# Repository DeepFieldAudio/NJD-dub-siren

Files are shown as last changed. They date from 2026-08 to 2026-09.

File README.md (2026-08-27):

Hello!

All you have here is the work on wich i spent countless hours and that i'm really happy to share with you.
If you are about to make your own version of this preamp, please share it Under the same conditions as i did.
Also, if you happen to discover mistakes that i made, or ways to improve the design, or you just built your own NJD,
then please share it with me and the rest of the world. I would love to see your builds!!

NJD V1 DOC.pdf is the complete documentation, it includes schematic, BOM, details of the pcb, wiring diagram,
and a buying list allowing you to directly access a basket at tme.eu.
GERBER NJD V1.zip is the file you need to upload on the website of the pcb manufacturer of your choice to get the pcb built.
ibom.html is an interactive bom, making it easier to build the pcb
you will also find all the kicad files that you can use to make your own mods of the design

contact me at deep field audio on instagram and facebook

this work shall remain open source and free.

Nélo Breuiller

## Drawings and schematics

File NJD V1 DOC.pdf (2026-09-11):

# DEEP FIELD

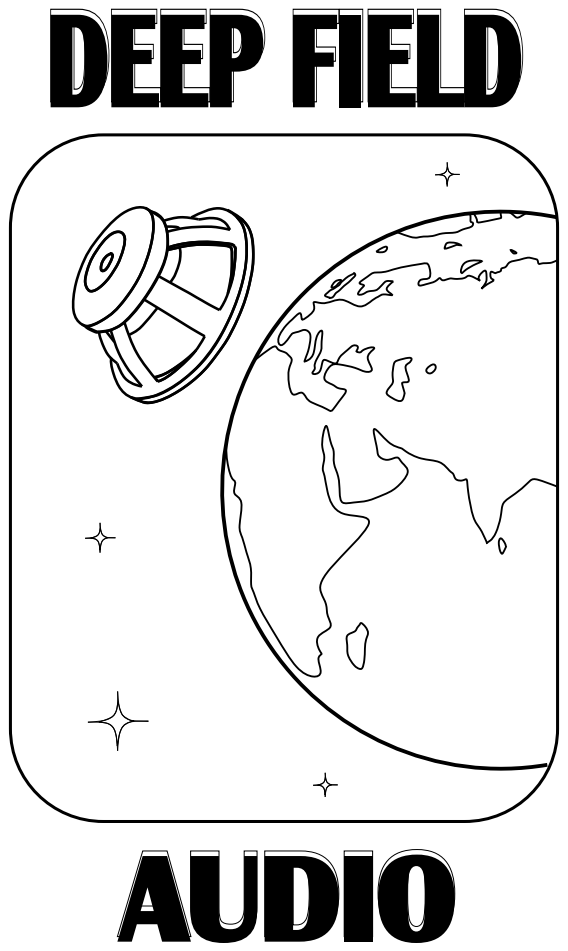
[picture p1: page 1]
AUDIO

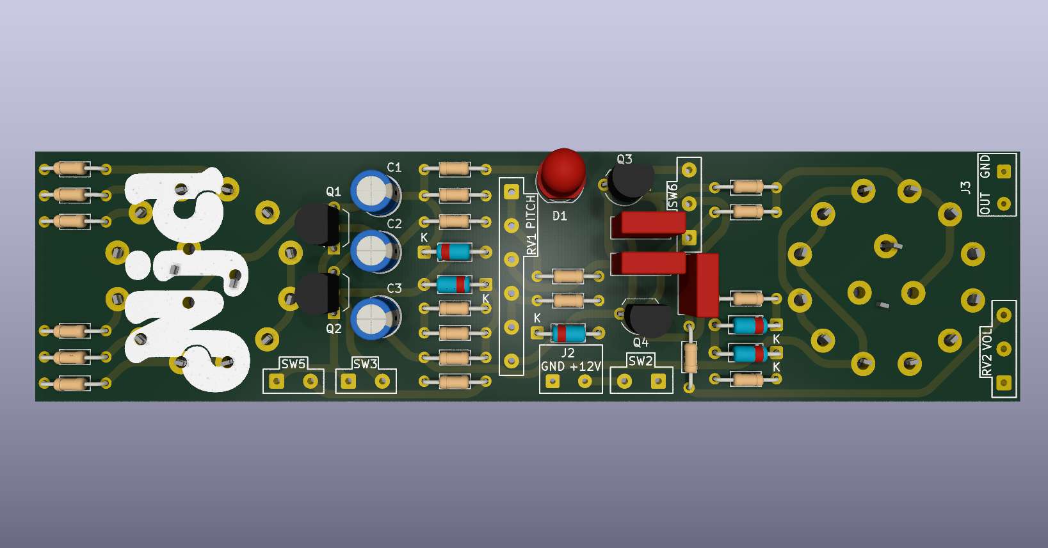
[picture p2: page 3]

1 | 2 | 3 | 4 | 5 | 6

AB

C

D

AB

C

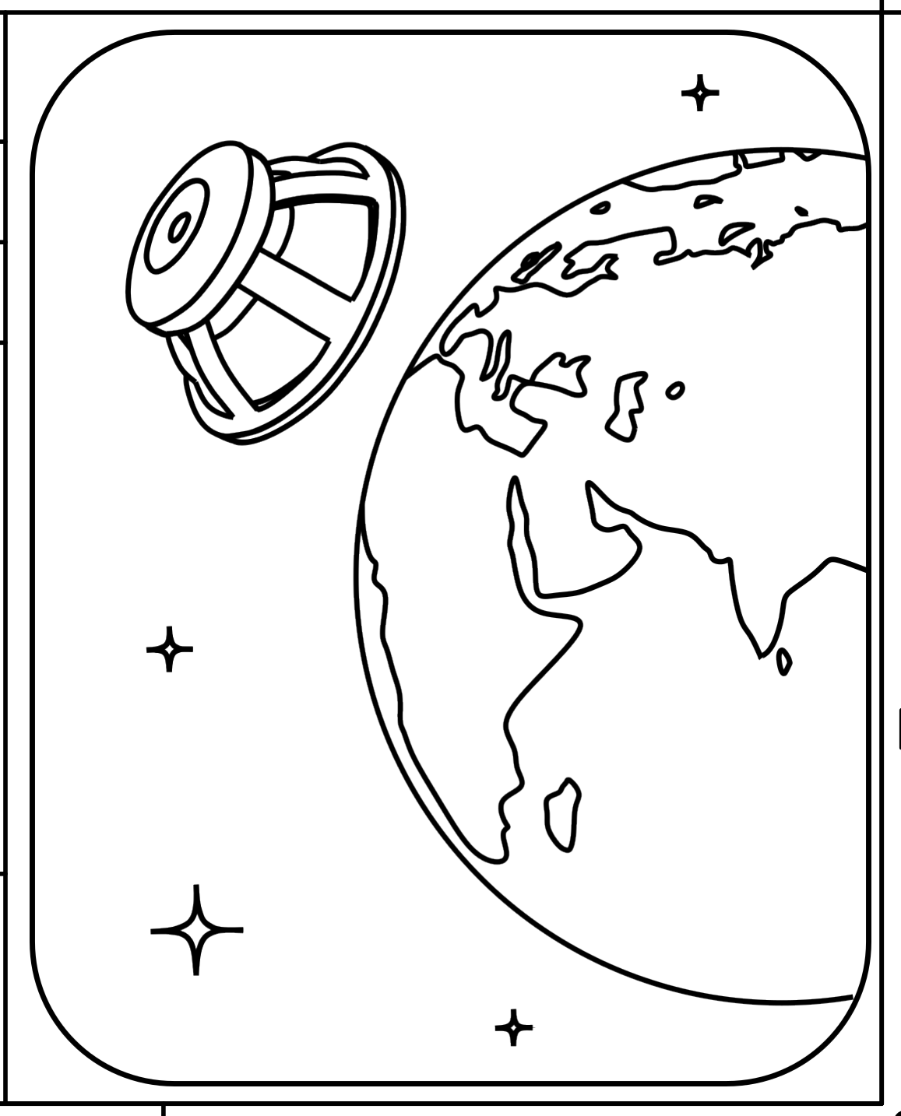
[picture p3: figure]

D Date: 2026-08-24
Rev: 1

Size: A4

NJD

Sheet: /

Page: 1/3

schematic

File: schematic.kicad_sch | wiring

File: wiring.kicad_sch

## 2 GND

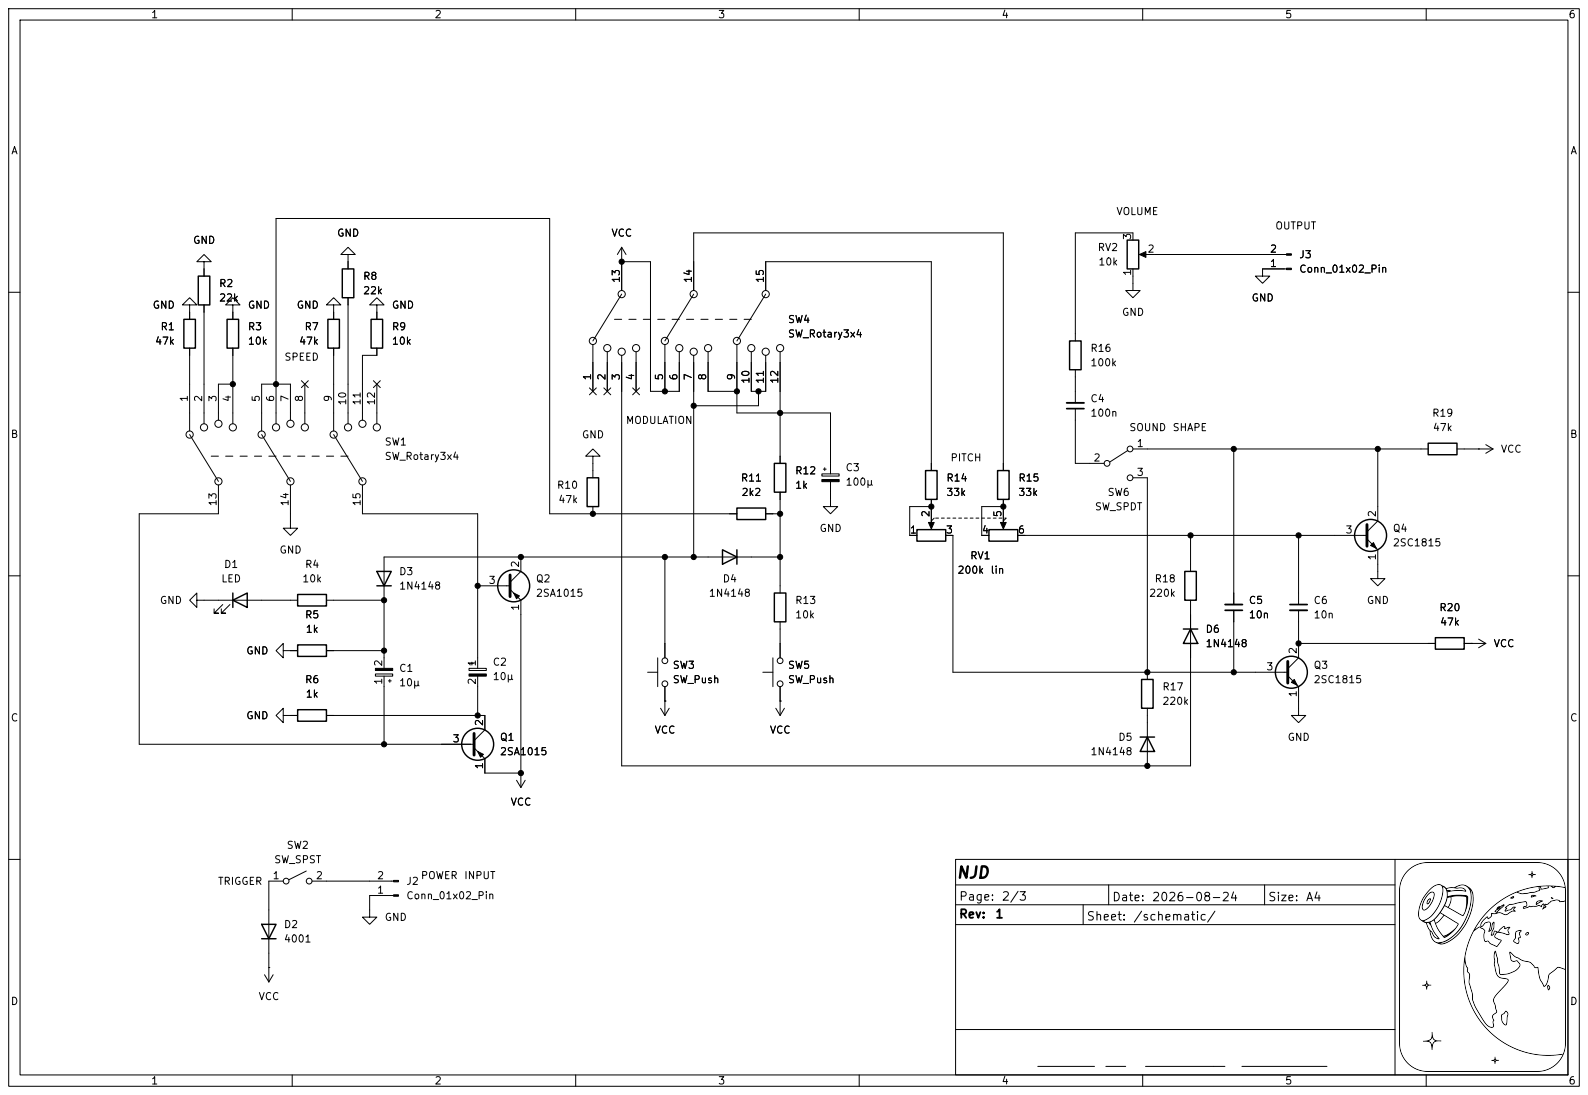
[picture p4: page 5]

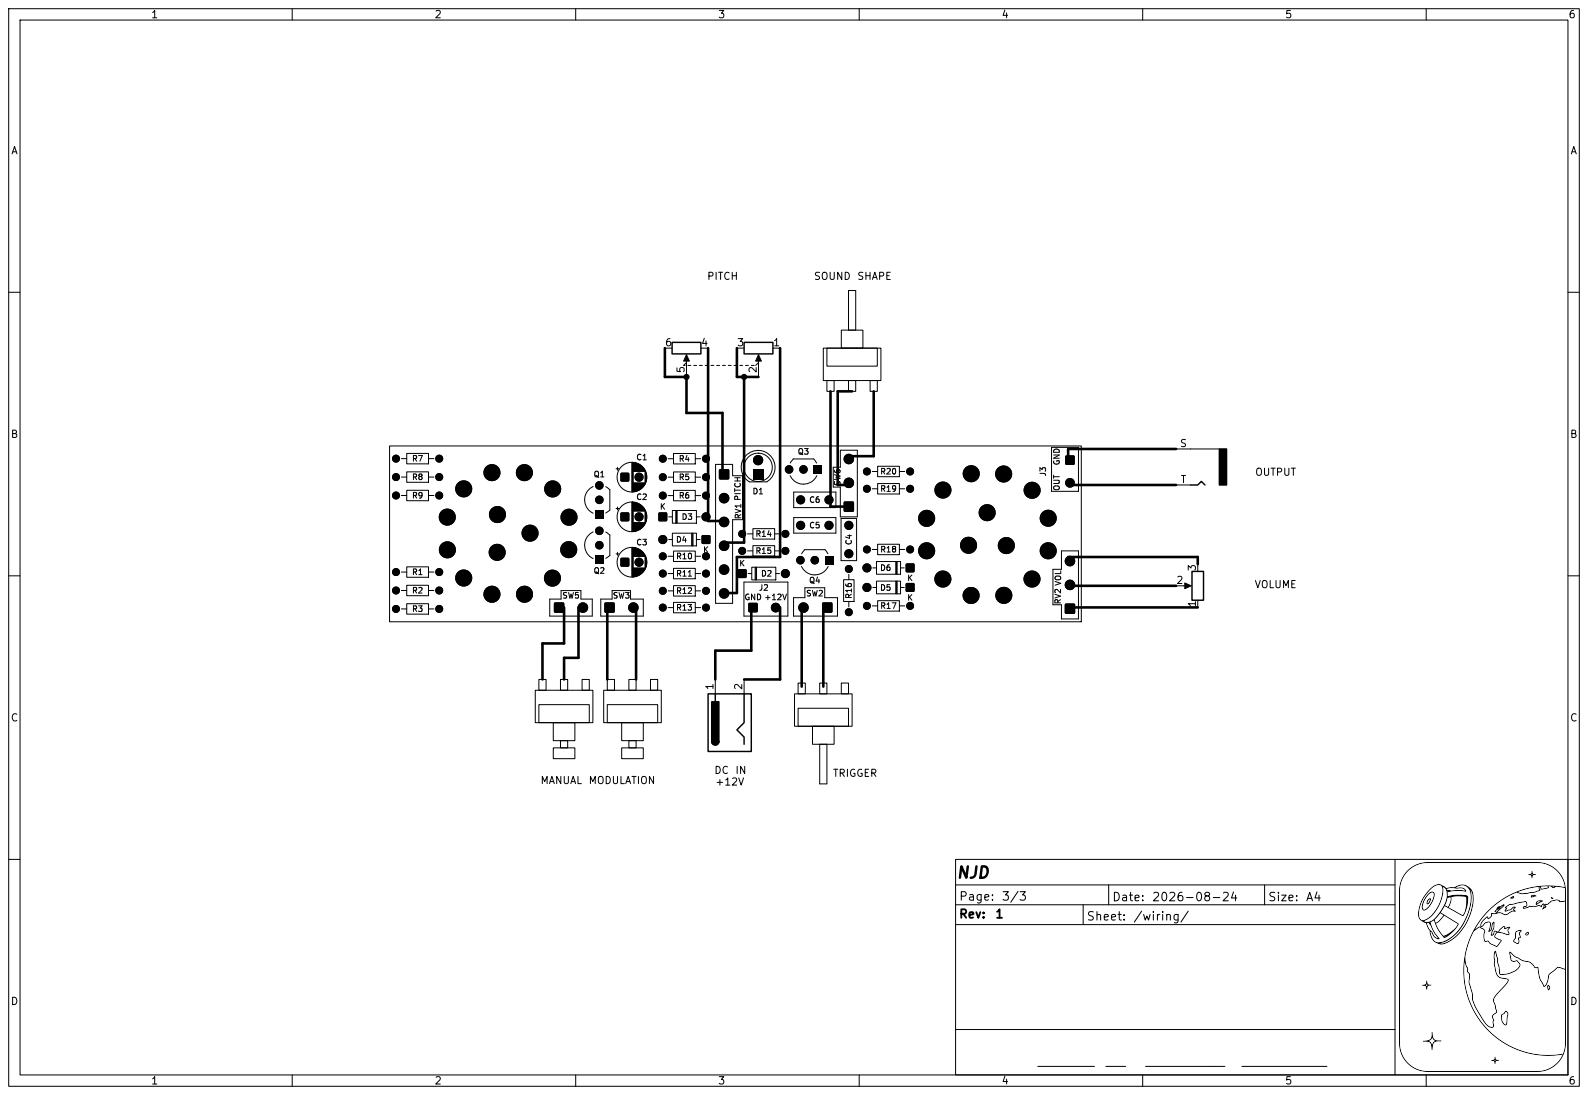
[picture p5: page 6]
D Date: 2026-08-24; Rev: 1; Size: A4; NJD; Sheet: /wiring/; Page: 3/3; SOUND SHAPE; VOLUME PITCH; OUTPUT

TRIGGER MANUAL MODULATION

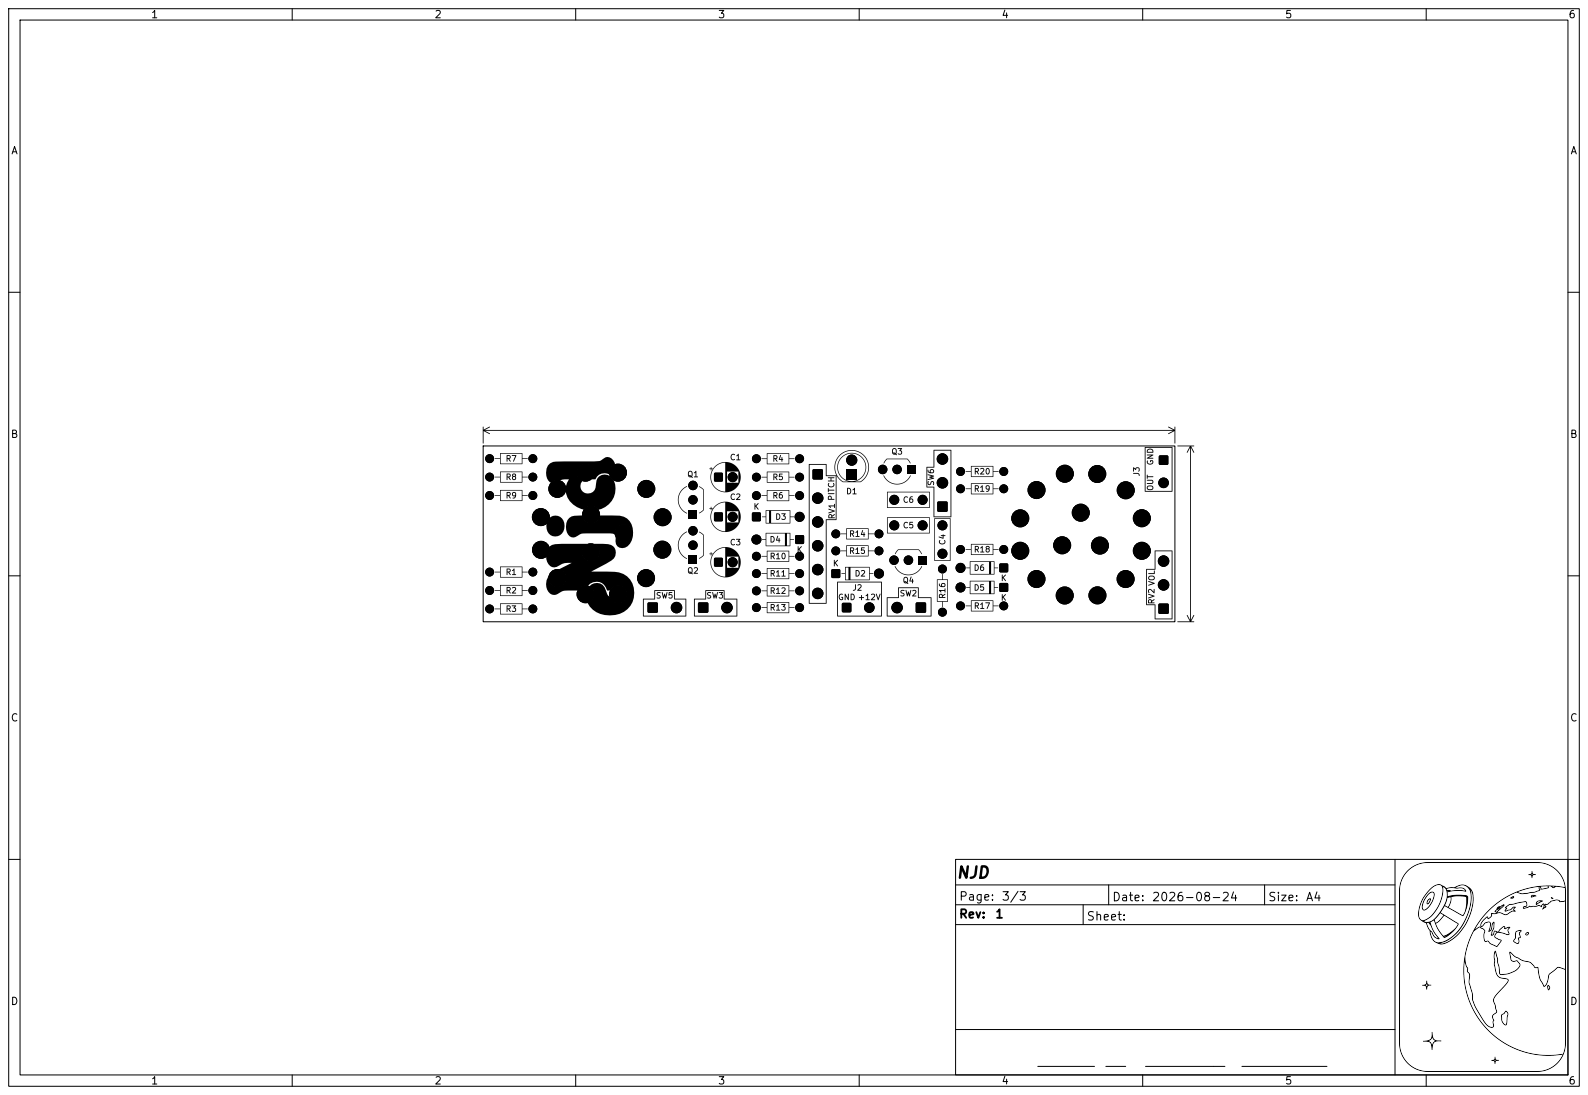
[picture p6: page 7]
D Date: 2026-08-24; Rev: 1; Size: A4; NJD; Sheet:; Page: 3/3

Referenrce | Qty | Value
C1,C2 | 2 10µF
C3 | 1 100µF
C4 | 1 100nF
C5,C6 | 2 10nF
D1 | 1 LED
D2 | 1 1N4001
D3,D4,D5,D6 | 4 1N4148
J1 | 1 JACK
J4 | 1 Jack-DC
Q1,Q2 | 2 2SA1015
Q3,Q4 | 2 2SC1815
R1,R7,R10,R19,R20 | 5 47k
R2,R8 | 2 22k
R3,R4,R9,R13 | 4 10k
R5,R6,R12 | 3 1k
R11 | 1 2k2
R14,R15 | 2 33k
R16 | 1 100k
R17,R18 | 2 220k
RV1 | 1 200k dual lin
RV2 | 1 10k log
SW1,SW4 | 2 rotary switch 4P3T
SW2 | 1 SPST
SW3,SW5 | 2 push switch momentary
SW6 | 1 SPDT

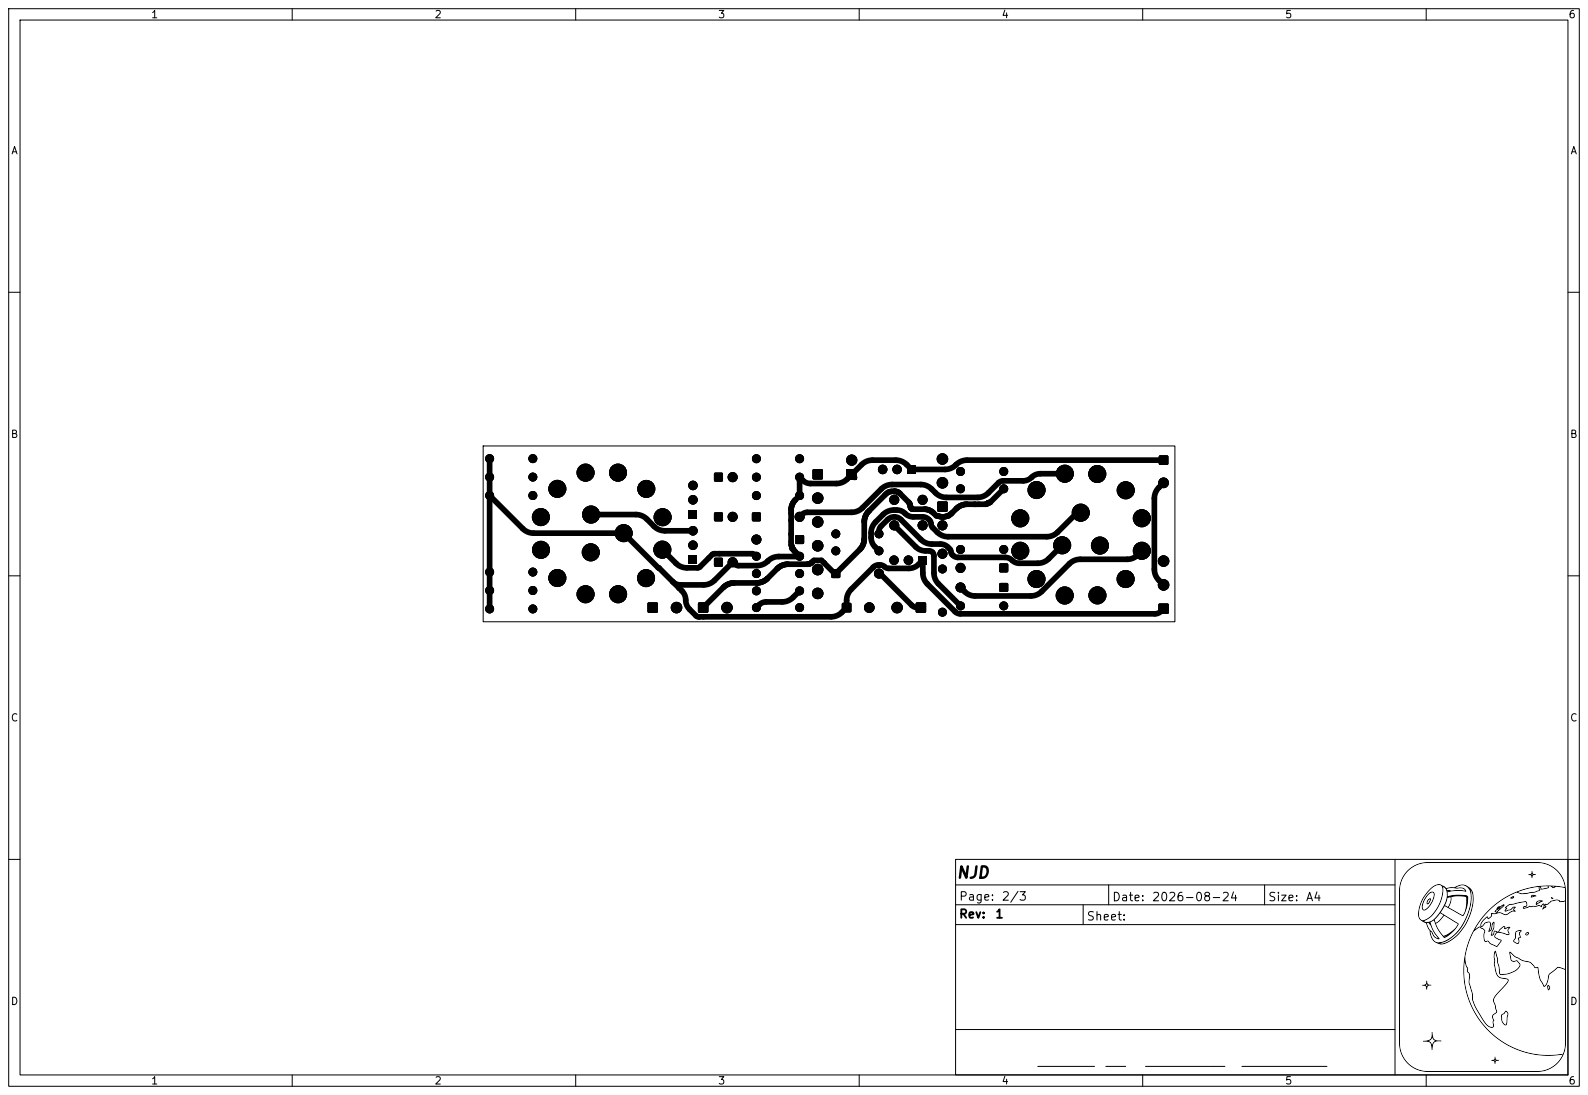
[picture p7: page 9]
D Date: 2026-08-24; Rev: 1; Size: A4; NJD; Sheet:; Page: 2/3

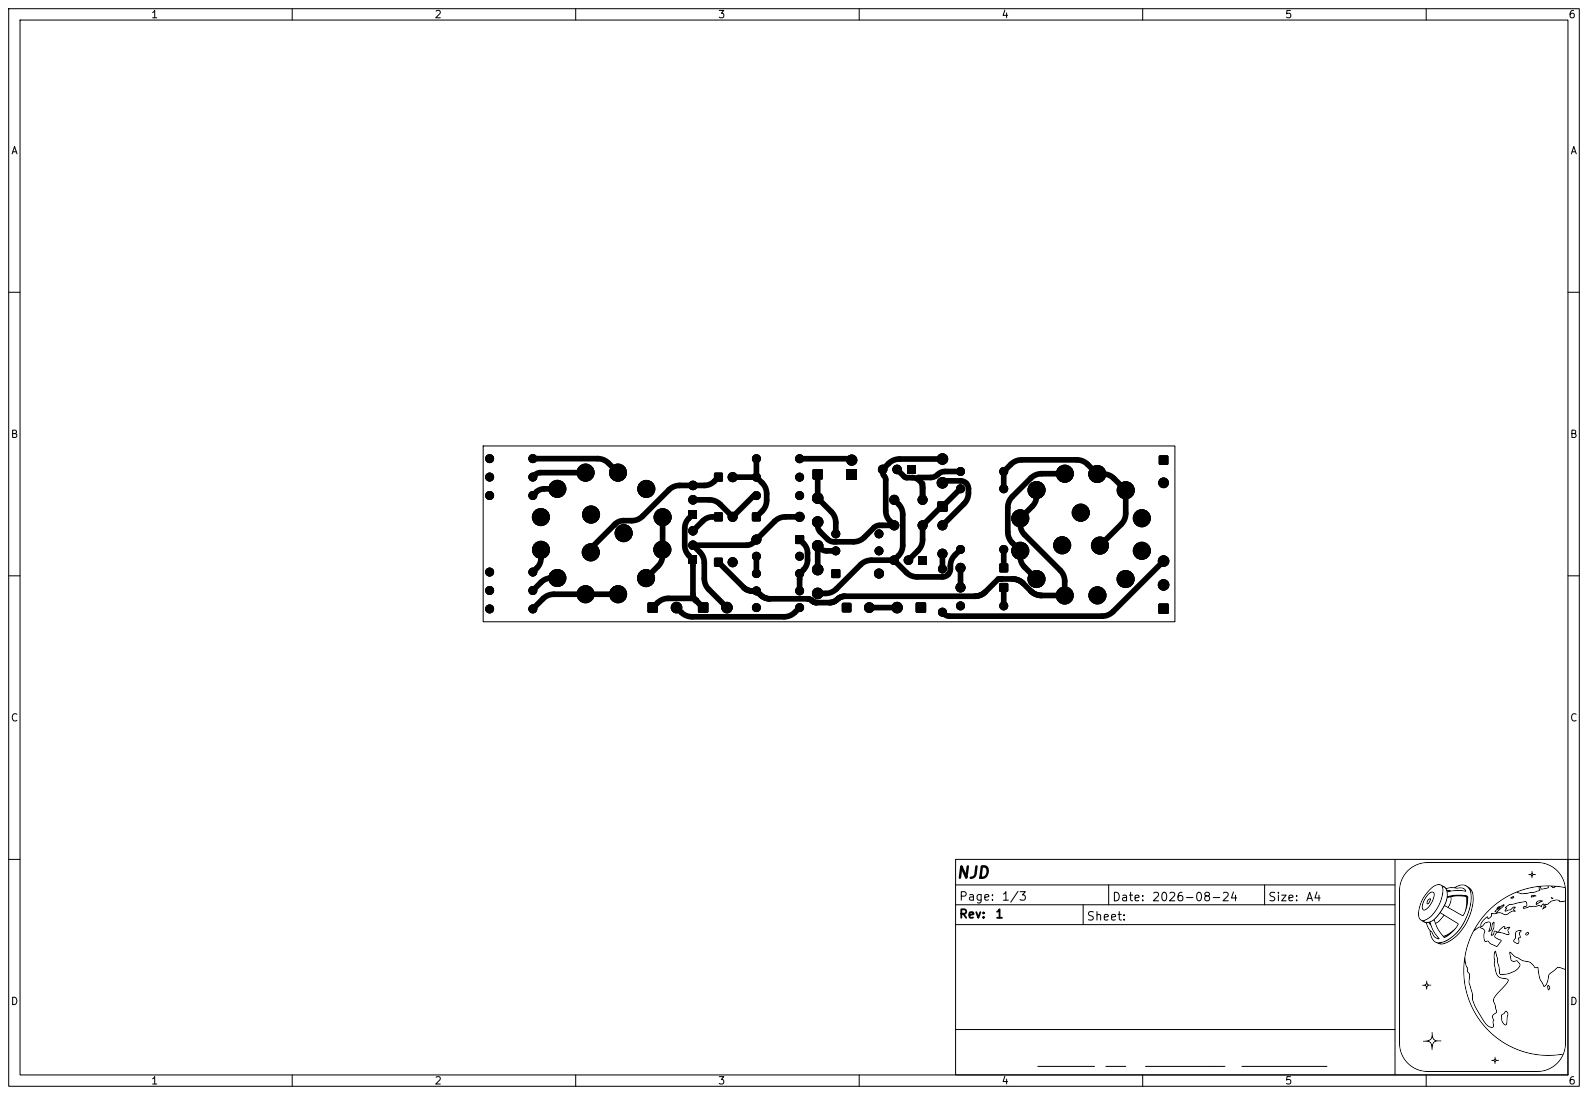
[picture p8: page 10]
D Date: 2026-08-24; Rev: 1; Size: A4; NJD; Sheet:; Page: 1/3

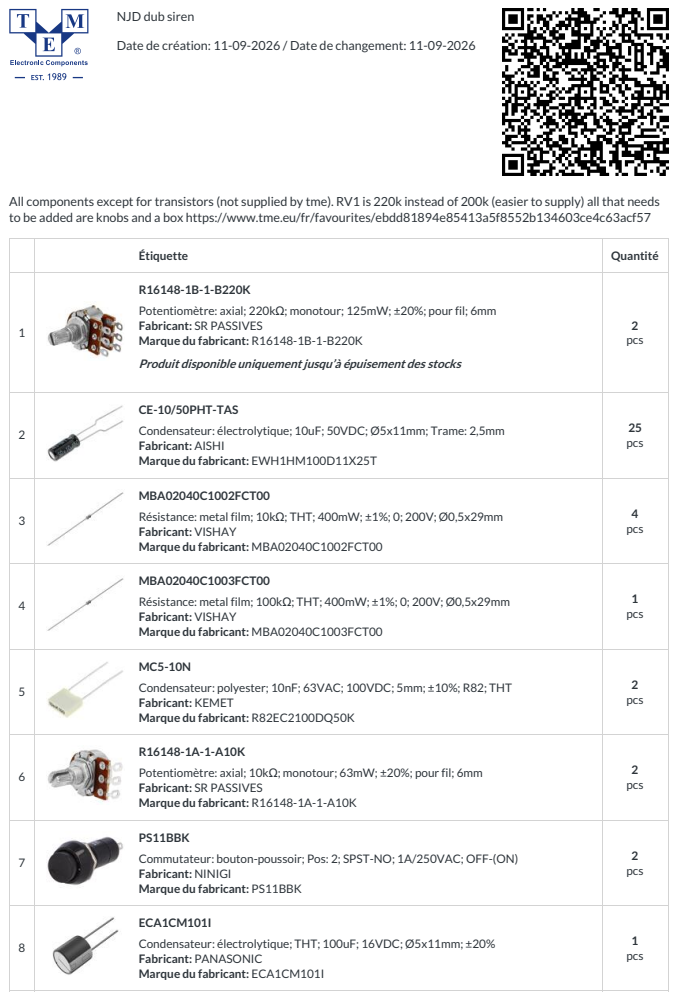
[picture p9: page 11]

NJD dub siren

Date de création: 11-09-2026 / Date de changement: 11-09-2026

All components except for transistors (not supplied by tme). RV1 is 220k instead of 200k (easier to supply) all that needs
to be added are knobs and a box https://www.tme.eu/fr/favourites/ebdd81894e85413a5f8552b134603ce4c63acf57

Étiquette | Quantité

1 | R16148-1B-1-B220K Potentiomètre: axial; 220kΩ; monotour; 125mW; ±20%; pour fil; 6mm Fabricant: SR PASSIVES Marque du fabricant: R16148-1B-1-B220K Produit disponible uniquement jusqu’à épuisement des stocks | 2 pcs

2 | CE-10/50PHT-TAS Condensateur: électrolytique; 10uF; 50VDC; Ø5x11mm; Trame: 2,5mm Fabricant: AISHI Marque du fabricant: EWH1HM100D11X25T | 25 pcs

3 | MBA02040C1002FCT00 Résistance: metal film; 10kΩ; THT; 400mW; ±1%; 0; 200V; Ø0,5x29mm Fabricant: VISHAY Marque du fabricant: MBA02040C1002FCT00 | 4 pcs

4 | MBA02040C1003FCT00 Résistance: metal film; 100kΩ; THT; 400mW; ±1%; 0; 200V; Ø0,5x29mm Fabricant: VISHAY Marque du fabricant: MBA02040C1003FCT00 | 1 pcs

5 | MC5-10N Condensateur: polyester; 10nF; 63VAC; 100VDC; 5mm; ±10%; R82; THT Fabricant: KEMET Marque du fabricant: R82EC2100DQ50K | 2 pcs

6 | R16148-1A-1-A10K Potentiomètre: axial; 10kΩ; monotour; 63mW; ±20%; pour fil; 6mm Fabricant: SR PASSIVES Marque du fabricant: R16148-1A-1-A10K | 2 pcs

7 | PS11BBK Commutateur: bouton-poussoir; Pos: 2; SPST-NO; 1A/250VAC; OFF-(ON) Fabricant: NINIGI Marque du fabricant: PS11BBK | 2 pcs

8 | ECA1CM101I Condensateur: électrolytique; THT; 100uF; 16VDC; Ø5x11mm; ±20% Fabricant: PANASONIC Marque du fabricant: ECA1CM101I | 1 pcs

| Étiquette | Quantité
9 | MC5-100N Condensateur: polyester; 100nF; 40VAC; 63VDC; 5mm; ±10%; R82; THT Fabricant: KEMET Marque du fabricant: R82DC3100DQ50K | 1 pcs
10 | MBA02040C2201FCT00 Résistance: metal film; 2,2kΩ; THT; 400mW; ±1%; 0; 200V; Ø0,5x29mm Fabricant: VISHAY Marque du fabricant: MBA02040C2201FCT00 | 1 pcs
11 | L-53ID LED; rouge; 5mm; 12,5÷80mcd; 60°; Front: convexe; 2÷2,5VDC Fabricant: KINGBRIGHT ELECTRONIC Marque du fabricant: L-53ID | 5 pcs
12 | CK1051 Commutateur: rotatif; Pos: 4; 1A/24VAC; 1A/24VDC; Nb.de séctions: 3 Fabricant: LORLIN Marque du fabricant: CK1051 | 2 pcs
13 | MBA02040C1001FCT00 Résistance: metal film; 1kΩ; THT; 400mW; ±1%; 0; 200V; Ø0,5x29mm Fabricant: VISHAY Marque du fabricant: MBA02040C1001FCT00 | 3 pcs
14 | MBA02040C2202FCT00 Résistance: metal film; 22kΩ; THT; 400mW; ±1%; 0; 200V; Ø0,5x29mm Fabricant: VISHAY Marque du fabricant: MBA02040C2202FCT00 | 2 pcs
15 | ACJM-MVS-2S Connecteur: Jack 6,3mm; socle; femelle; mono; pistes: 2; droit Fabricant: AMPHENOL Marque du fabricant: ACJM-MVS-2S | 1 pcs
16 | 1N4148-DIO Diode: commutation; THT; 100V; 0,2A; Ifsm: 4A; DO35; Ammo Pack; 500mW Fabricant: DIOTEC SEMICONDUCTOR Marque du fabricant: 1N4148 | 4 pcs
17 | TSM113F1 Commutateur: à levier; Pos: 3; SP3T; ON-OFF-(ON); 3A/250VAC; 20mΩ Fabricant: NINIGI Marque du fabricant: TSM113F1 | 1 pcs
18 | 1N4001-DIO Diode: redresseuse; THT; 50V; 1A; Ifsm: 27A; DO204AC,DO41; Ammo Pack Fabricant: DIOTEC SEMICONDUCTOR Marque du fabricant: 1N4001 | 1 pcs
19 | MBA02040C4702FCT00 Résistance: metal film; 47kΩ; THT; 400mW; ±1%; 0; 200V; Ø0,5x29mm Fabricant: VISHAY Marque du fabricant: MBA02040C4702FCT00 | 5 pcs
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

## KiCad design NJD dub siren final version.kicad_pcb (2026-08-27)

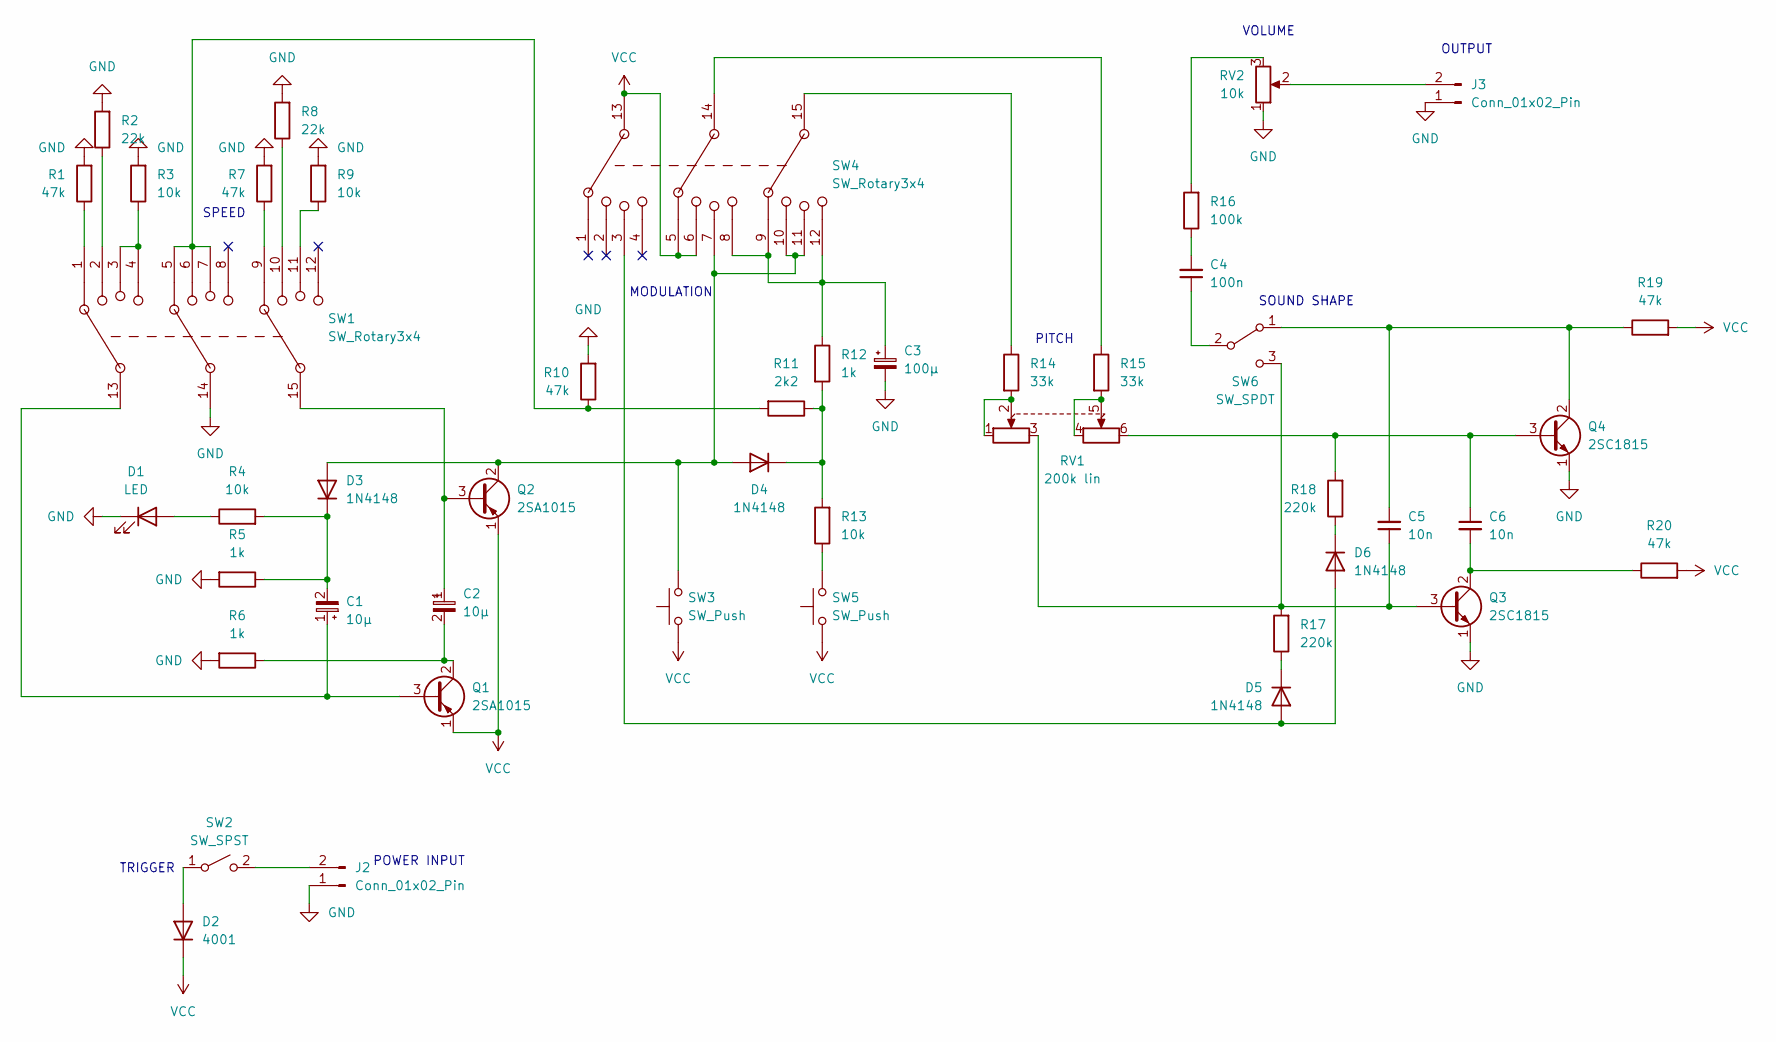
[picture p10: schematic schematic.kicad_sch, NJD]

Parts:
C1, C2: 10µ; CP_Radial_D5.0mm_P2.50mm
C3: 100µ; CP_Radial_D5.0mm_P2.50mm
C4: 100n; C_Rect_L7.2mm_W2.5mm_P5.00mm_FKS2_FKP2_MKS2_MKP2
C5, C6: 10n; C_Rect_L7.2mm_W2.5mm_P5.00mm_FKS2_FKP2_MKS2_MKP2
D1: LED; LED_D5.0mm
D2: 4001; D_DO-35_SOD27_P7.62mm_Horizontal
D3, D4, D5, D6: 1N4148; D_DO-35_SOD27_P7.62mm_Horizontal
J2, J3: Conn_01x02_Pin; SolderWire-0.15sqmm_1x02_P4mm_D0.5mm_OD1.5mm
Q1, Q2: 2SA1015; TO-92_Inline_Wide
Q3, Q4: 2SC1815; TO-92_Inline_Wide
R1, R7, R10, R19, R20: 47k; R_Axial_DIN0204_L3.6mm_D1.6mm_P7.62mm_Horizontal
R2, R8: 22k; R_Axial_DIN0204_L3.6mm_D1.6mm_P7.62mm_Horizontal
R3, R4, R9, R13: 10k; R_Axial_DIN0204_L3.6mm_D1.6mm_P7.62mm_Horizontal
R5, R6, R12: 1k; R_Axial_DIN0204_L3.6mm_D1.6mm_P7.62mm_Horizontal
R11: 2k2; R_Axial_DIN0204_L3.6mm_D1.6mm_P7.62mm_Horizontal
R14, R15: 33k; R_Axial_DIN0204_L3.6mm_D1.6mm_P7.62mm_Horizontal
R16: 100k; R_Axial_DIN0204_L3.6mm_D1.6mm_P7.62mm_Horizontal
R17, R18: 220k; R_Axial_DIN0204_L3.6mm_D1.6mm_P7.62mm_Horizontal
RV1: 200k lin; SolderWire-0.25sqmm_1x06_P4.2mm_D0.65mm_OD1.7mm
RV2: 10k; SolderWire-0.25sqmm_1x03_P4.2mm_D0.65mm_OD1.7mm
SW1, SW4: SW_Rotary3x4; 3P4T rotary switch
SW2: SW_SPST; SolderWire-0.25sqmm_1x02_P4.2mm_D0.65mm_OD1.7mm
SW3, SW5: SW_Push; SolderWire-0.25sqmm_1x02_P4.2mm_D0.65mm_OD1.7mm
SW6: SW_SPDT; SolderWire-0.25sqmm_1x03_P4.2mm_D0.65mm_OD1.7mm

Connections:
GND: C3.2, D1.1 (K), J2.1, J3.1, Q3.1 (E), Q4.1 (E), R1.2, R2.2, R3.2, R5.2, R6.2, R7.2, R8.2, R9.2, R10.2, RV2.1, SW1.14
unnamed: C3.1, R12.1, SW4.8, SW4.9, SW4.12
unnamed: C4.2, R16.1
unnamed: D1.2 (A), R4.1
unnamed: D2.2 (A), SW2.1 (A)
unnamed: D3.2 (A), D4.2 (A), Q2.2 (C), SW3.2, SW4.7, SW4.10, SW4.11
unnamed: C1.2, D3.1 (K), R4.2, R5.1
unnamed: D4.1 (K), R11.1, R12.2, R13.2
unnamed: D5.2 (A), D6.2 (A), SW4.3
unnamed: D5.1 (K), R17.1
unnamed: D6.1 (K), R18.1
unnamed: J2.2, SW2.2 (B)
unnamed: J3.2, RV2.2
unnamed: C1.1, Q1.3 (B), SW1.13
unnamed: C2.2, Q1.2 (C), R6.1
unnamed: C2.1, Q2.3 (B), SW1.15
unnamed: C5.1, Q3.3 (B), R17.2, RV1.3, SW6.3 (C)
unnamed: C6.2, Q3.2 (C), R20.1
unnamed: C6.1, Q4.3 (B), R18.2, RV1.6
unnamed: C5.2, Q4.2 (C), R19.1, SW6.1 (A)
unnamed: R1.1, SW1.1
unnamed: R2.1, SW1.2
unnamed: R3.1, SW1.3, SW1.4
unnamed: R7.1, SW1.9
unnamed: R8.1, SW1.10
unnamed: R9.1, SW1.11
unnamed: R10.1, R11.2, SW1.5, SW1.6, SW1.7
unnamed: R13.1, SW5.2
unnamed: R14.1, SW4.15
unnamed: R14.2, RV1.1, RV1.2
unnamed: R15.1, SW4.14
unnamed: R15.2, RV1.4, RV1.5
unnamed: R16.2, RV2.3
unnamed: C4.1, SW6.2 (B)
VCC: D2.1 (K), Q1.1 (E), Q2.1 (E), R19.2, R20.2, SW3.1, SW4.5, SW4.6, SW4.13, SW5.1

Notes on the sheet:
VOLUME
PITCH
SOUND SHAPE
TRIGGER
OUTPUT
MODULATION
POWER INPUT
SPEED

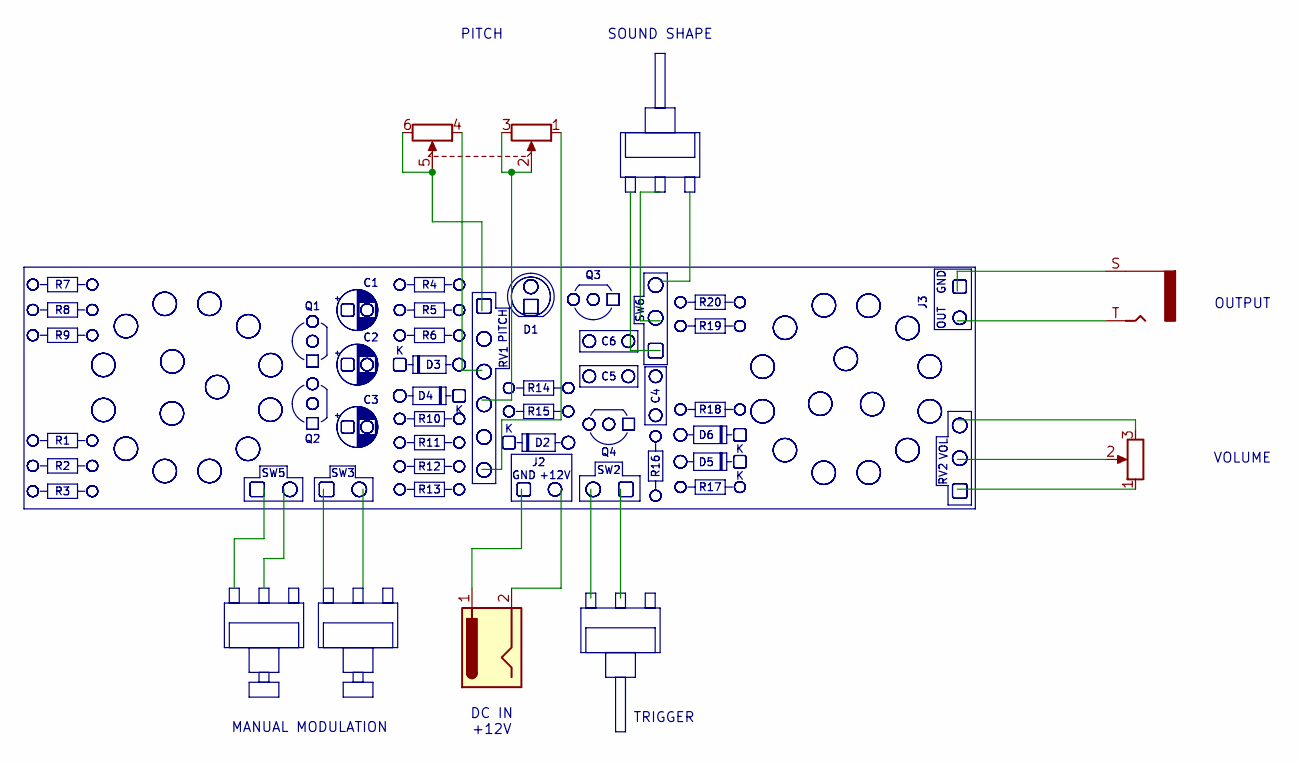
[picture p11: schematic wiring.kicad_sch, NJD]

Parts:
J1: AudioJack2
J4: Jack-DC
RV3: R_Potentiometer
RV4: R_Potentiometer_Dual

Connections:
unnamed: RV4.2, RV4.3
unnamed: RV4.5, RV4.6

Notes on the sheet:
PITCH
DC IN +12V
TRIGGER
MANUAL MODULATION
SOUND SHAPE
OUTPUT
VOLUME

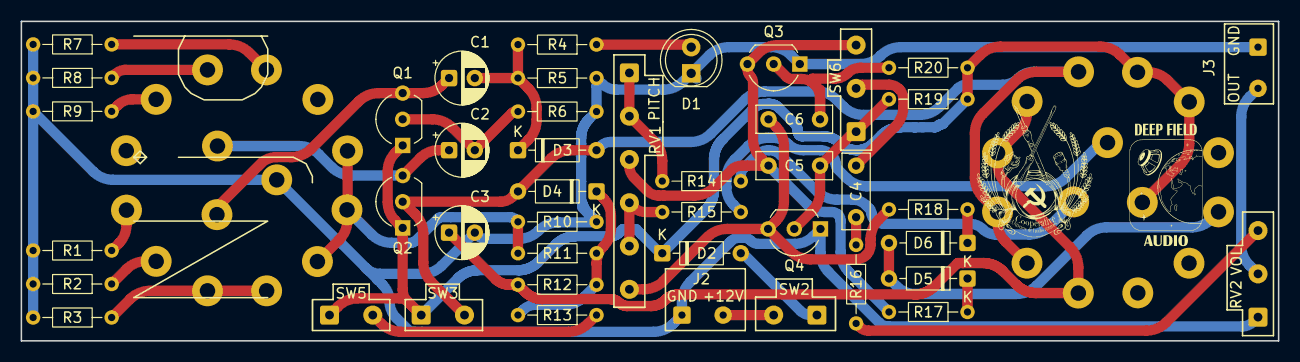
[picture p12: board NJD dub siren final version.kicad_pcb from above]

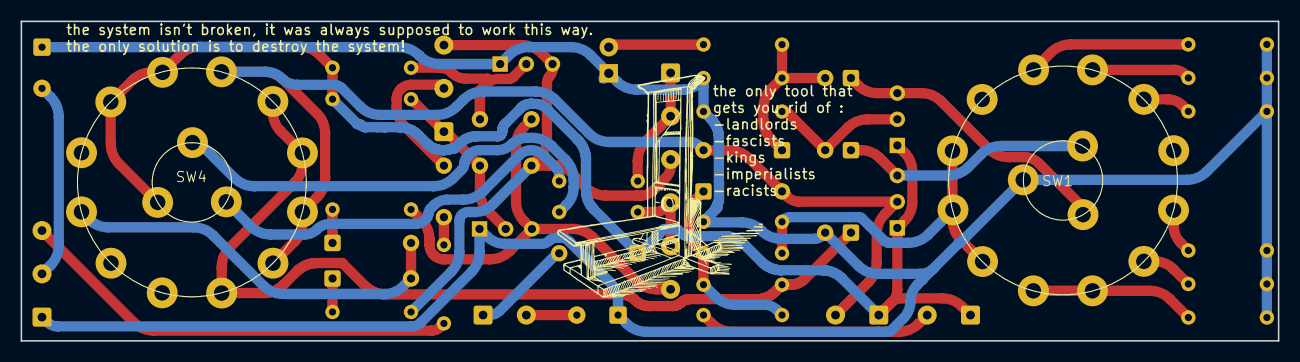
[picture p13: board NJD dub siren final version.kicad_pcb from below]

Board: 2 copper layers, 122.0 x 31.0 mm, 46 parts (2 on the bottom side), 35 nets.
